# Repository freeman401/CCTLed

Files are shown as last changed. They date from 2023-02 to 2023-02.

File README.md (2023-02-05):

# CCTLed
A simple CCT Led strip driver with IR remote

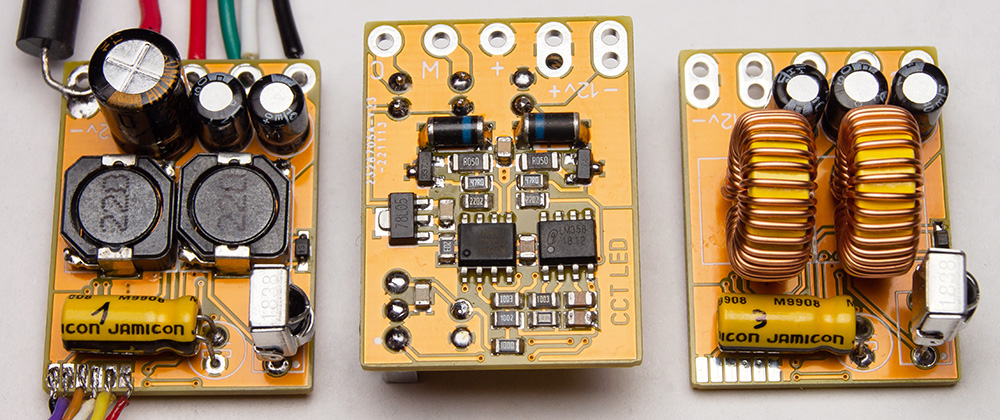
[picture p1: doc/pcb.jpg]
PCB photo(slightly older revision)


## Features and capabilities:
- High PWM frequency, low ripple, low EMI, **no flicker**
- Full range of brightness and temperature control
- Settings are retained in EEPROM
- 12 presets (4 levels of brightness * 3 values of temperature)
- Soft turn-on and turn-off
- Has constant supply current regulation (ultimately the brightness depends on the input voltage)
- Can handle up to ~50W of total maximum output power for 12V led strip (2A per channel)

Higher input voltage can be used, up to 24V, assuming the appropriate input capacitor voltage and proper power consumption calibration.

The driver is supposed to be used with this kind of generic 21-key IR remote:
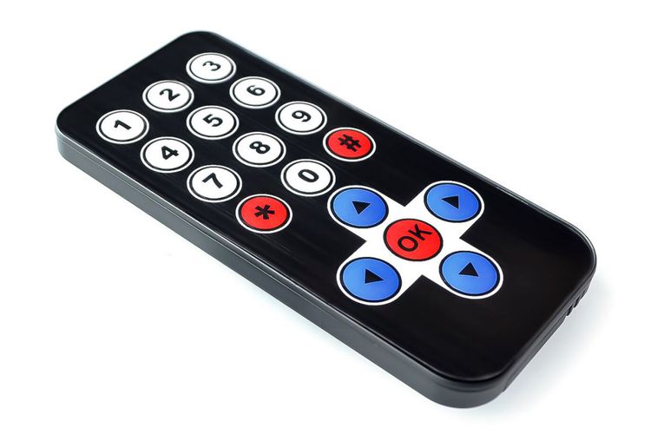
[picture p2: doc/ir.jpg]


Any other NEC protocol remote can be used, appropriate keycodes must be assigned in the firmware.

## Firmware upload
It is recommended to use [Arduino IDE](https://www.arduino.cc/en/software) with an external programmer. [MicroCore](https://github.com/MCUdude/MicroCore) is required. Add a custom clock configuration to 'boards.txt' and select it:
```
13.menu.clock.9M60=9.6 MHz internal osc. 0ms start delay
13.menu.clock.9M60.bootloader.low_fuses=0b0{bootloader.eesave_bit}110010
13.menu.clock.9M60.build.f_cpu=9600000L
```
Otherwise, the driver will blink every time it is turned on. Alternatively, you could solder a 10k resistor in parallel to each mosfet gate to prevent it from opening while the MCU pins are in Hi-z state.

Each driver **needs to be manually calibrated** because it uses the ADC's internal 1.1V reference, which is stable but not at all accurate initially. Calibration values can be loaded from EEPROM (although this is disabled by default).

## Circuit diagram
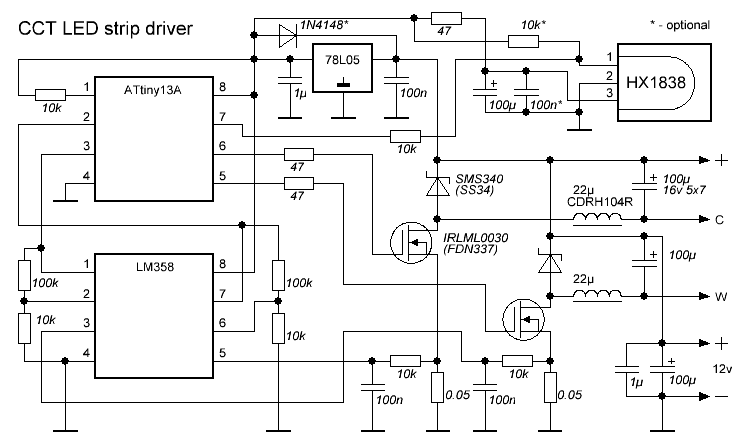
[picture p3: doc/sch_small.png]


Gerber files are provided:

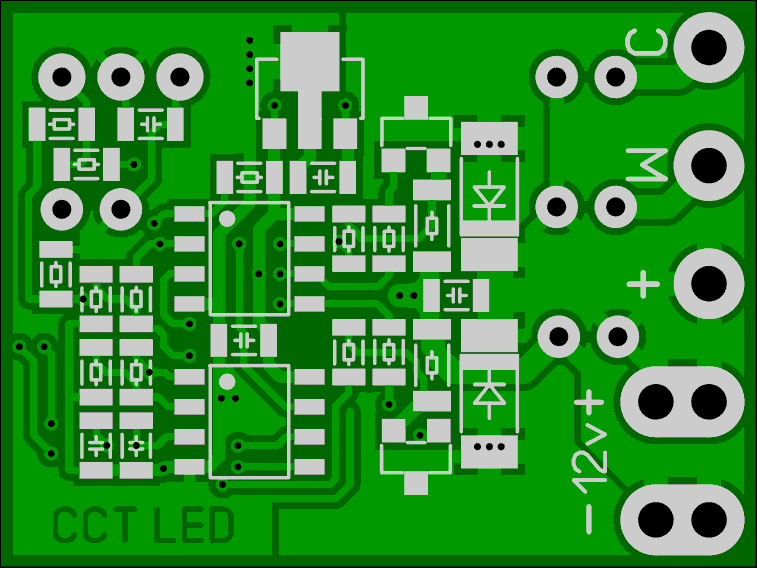
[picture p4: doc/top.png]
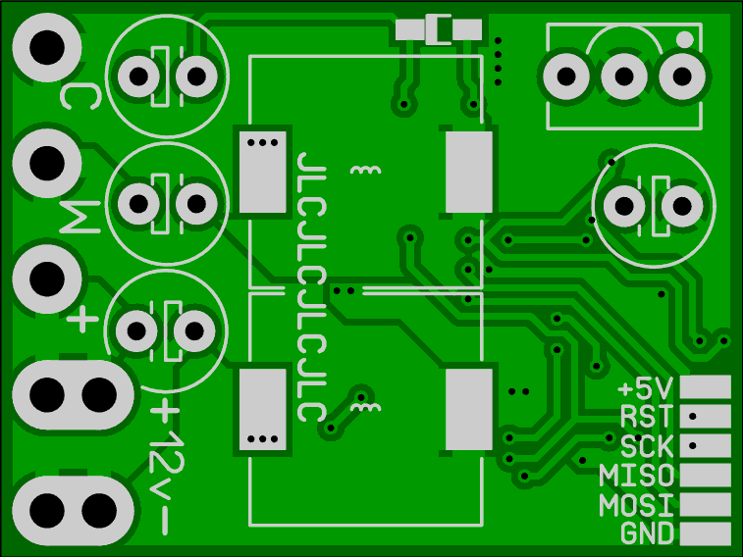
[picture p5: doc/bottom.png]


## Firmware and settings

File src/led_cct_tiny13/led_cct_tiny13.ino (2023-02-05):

/*
CCTLed - A simple CCT Led strip driver with IR remote
Copyright (C) 2023 freeman401
Copyright (C) 2013 FastLED (scale8 routine)
Copyright (C) 2021 AlexGyver (NEC decoding routine)

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
You should have received a copy of the GNU General Public License
along with this program.  If not, see <http://www.gnu.org/licenses/>.
*/

// 141 = ~1a @ vref 1.1v
// [device]: [maxpow] [coeff] - [max current, single strand operating] [max current, both strands operating] ([combined current])
// 1: 220 100 - 1.56a 1.19a (2.38a) @ 18v
// 2: 230 100 - 1.59a 1.19a (2.37a) @ 18v
// 3: 240 130 - 1.69a 1.69a (3.38a) @ 13.3v

//Calibration values:
// MAXPOW is used to set the maximum current of the single channel
// !!! MAXPOW > (255 - coeff) !!!
// Also keep it in 200-249 range; lower - less control precision; higher - regulation loop will break
// Better to calculate a proper resistor divider at lower powers
//
// COEFF is used to adjust the color temperature transition
// < 127 - closer to constant power during entire color temperature range, less light output, more linear temperature regulation
//   127 - full power in the middle of the temperature range, maximum light output, but nonlinear regulation
// > 127 - widens the the middle 'full power' spot, even more nonlinear
#define _MAXPOW       128 //240
#define _COEFF        127 //130

#define USE_EEPROM    0    // Use EEPROM for storage of calibration values, 0 saves 42 bytes

#define _MAXPOW_ADDR  0x00 // Put your settings here with external tools
#define _COEFF_ADDR   0x01

//======================================
#define _BRI_ADDR     0x20
#define _TMP_ADDR     0x21

// IR key codes
#define IR_1          0xA2 // 1010 0010
#define IR_2          0x62 // 0110 0010
#define IR_3          0xE2 // 1110 0010
#define IR_4          0x22 // 0010 0010
#define IR_5          0x02 // 0000 0010
#define IR_6          0xC2 // 1100 0010
#define IR_7          0xE0 // 1110 0000
#define IR_8          0xA8 // 1010 1000
#define IR_9          0x90 // 1001 0000
#define IR_STAR       0x68 // 0110 1000
#define IR_0          0x98 // 1001 1000
#define IR_HASH       0xB0 // 1011 0000
#define IR_UP         0x18 // 0001 1000
#define IR_LEFT       0x10 // 0001 0000
#define IR_OK         0x38 // 0011 1000
#define IR_RIGHT      0x5A // 0101 1010
#define IR_DOWN       0x4A // 0100 1010

const PROGMEM uint8_t acmd[] = { IR_1, IR_2, IR_3, IR_4, IR_5, IR_6, IR_7, IR_8, IR_9, IR_STAR, IR_0, IR_HASH/*, IR_UP, IR_DOWN, IR_LEFT, IR_RIGHT */};
const PROGMEM uint8_t abri[] = { 31, 63, 127, 255 }; // effective values: 31, 31, 31, 63, 63, 63, 127, 127, 127, 255, 255, 255
const PROGMEM uint8_t atmp[] = { 0, 127, 255 }; // effective values: 0, 127, 255, 0, 127, 255, 0, 127, 255, 0, 127, 255

// 1/(37500Hz/3) = 80μs
#define _NEC_TOLERANCE      3   //2   // High/low tolerance, 160μs
#define _NEC_TOLERANCE2     25  //19  // Start/repeat tolerance, 1520μs
#define _NEC_SKIP_REPEAT    0   //2   // First N repeats to skip

// NEC timings
#define _NEC_HIGH_BIT       28  // 2250μs
#define _NEC_LOW_BIT        14  // 1150μs
#define _NEC_START_BIT      169 //180 // 14400μs
#define _NEC_REPEAT         141 //153 // 12300μs
#define _NEC_REPEAT_TIMEOUT 187 // 15000μs

#define _NEC_HIGH_MIN   (_NEC_HIGH_BIT - _NEC_TOLERANCE)
#define _NEC_HIGH_MAX   (_NEC_HIGH_BIT + _NEC_TOLERANCE)
#define _NEC_LOW_MIN    (_NEC_LOW_BIT - _NEC_TOLERANCE)
#define _NEC_LOW_MAX    (_NEC_LOW_BIT + _NEC_TOLERANCE)
#define _NEC_START_MIN  (_NEC_START_BIT - _NEC_TOLERANCE2)
#define _NEC_START_MAX  (_NEC_START_BIT + _NEC_TOLERANCE2)
#define _NEC_REPEAT_MIN (_NEC_REPEAT - _NEC_TOLERANCE2)
#define _NEC_REPEAT_MAX (_NEC_REPEAT + _NEC_TOLERANCE2)

#if USE_EEPROM
  #define __MAXPOW maxpow
  #define __COEFF coeff
#else
  #define __MAXPOW _MAXPOW
  #define __COEFF _COEFF
#endif

uint8_t bufferL = 0;  // Receive buffer, low byte
uint8_t bufferH = 0;  // Receive buffer, high byte
uint8_t command = 0;  // Last received command
uint8_t time = 0;     // Last received pulse width
uint8_t counter = 0;  // Received bits counter
uint8_t repeats = 0;  // Repeats counter
bool start = false;   // Receive start
bool decoded = false; // Command is received, decoded and ready to be interpreted
bool repeat = false;  // Received command is a 'repeat'

uint8_t maxpow = 0;   // Maximum single channel current
uint8_t coeff = 0;    // CCT regulation coefficent
uint8_t upd = 0;      // Skip ADC value update counter
uint8_t adc = 0;      // Averaged ADC value
uint8_t setW = 0;     // Target current setting for warm channel
uint8_t setC = 0;     // Target current setting for cold channel
uint8_t bri = 0;      // Brightness setting
uint8_t tmp = 0;      // Temperature setting
bool toff = false;    // Output is being turned off
uint8_t eet = 0;      // EEPROM save timeout

uint8_t t = 0;        // f/3 divider counter
uint8_t t1 = 0;       // f/256 divider counter

ISR(TIM0_OVF_vect) {
  if(++t > 2) {            // Divide timer frequency by 3
    t = 0;
    if(time < 255) time++; // Measure the IR pulse width
    if(++t1 == 255) {      // Divide it further for EEPROM timeout counter
      t1 = 0;
      if(eet < 255) eet++;
    }
  }
}

ISR(PCINT0_vect) {
  if(PINB & (1 << PB2)) return;             // Falling edge interrupt
  if (start && time > _NEC_LOW_MIN && time < _NEC_HIGH_MAX) {  // Check general pulse width boundaries
    uint8_t state = 2; // This not-so-elegant solution results in a more compact binary for some reason
    if (time < _NEC_LOW_MAX) state = 0;
    if (time > _NEC_HIGH_MIN) state = 1;
    if (state < 2) {                        // Valid low or high bit is received
      bufferL = (bufferL << 1) | state;     // Fill the buffer
      if(counter == 23) bufferH = bufferL;  // High byte is received, continue with low byte
      if (++counter > 31) {                 // 32 bits received
        if (bufferH & bufferL) goto exit;   // Check data integrity
        command = bufferH;                  // Valid command is received
        decoded = true;
        start = false; 
        #if _NEC_SKIP_REPEAT                // Compiler is not smart enough to optimize this
          repeats = 0; 
        #endif 
        goto exit;
      }
    }
  }
  else if (time > _NEC_REPEAT_MIN && time < _NEC_REPEAT_MAX) { // Repeat detected
    #if _NEC_SKIP_REPEAT
      if (++repeats > _NEC_SKIP_REPEAT)
    #endif
      repeat = true;
  } 
  else if (time > _NEC_START_MIN && time < _NEC_START_MAX) {   // Packet start detected
    bufferL = 0;                                               // Reset everything
    counter = 0;
    start = true;
  }
  exit: time = 0;                           // Start measuring the next pulse width
}

ISR(ADC_vect) {  
  adc = adc / 2 + ADCH / 2;                 // Crude 'averaging' technique for better accuracy
  if(TCCR0A & ((1<<WGM01)|(1<<WGM00)) && ++upd > 150 - bri / 2) { // Current regulation should work only if PWM is enabled, also skip ADC cycles for accuracy and smooth fades
    uint8_t* ocrp = (uint8_t*)&OCR0A;       // Pointer to PWM register
    uint8_t* setp = &setW;                  // Pointer to target current value
    if(ADMUX & (1<<MUX0)) {                 // Cool/warm strand channel selection
      ocrp = (uint8_t*)&OCR0B;
      setp = &setC;
    }
    if(*setp < 4) *ocrp = *setp;            // Current regulation at low brightness doesn't go all the way to zero, so it is disabled
    else if(((adc > *setp && adc - *setp > 4) || toff) && *ocrp > 0) (*ocrp)--; // Adjust PWM to match ADC value with current target value
    else if(adc < *setp && *setp - adc > 1 && *ocrp < 255) (*ocrp)++;
    ADMUX ^= (1<<MUX0);                     // Switch to the other ADC channel
    if(toff && !(OCR0A | OCR0B)) {          // If both channels are off, disable PWM to prevent slight residual glow
      toff = false;
      TCCR0A &= ~((1<<WGM01)|(1<<WGM00));
    }
    upd = 0;
  }
  ADCSRA |= (1<<ADSC);                      // Restart ADC measurement
}

uint8_t scale8(uint8_t value, uint8_t scale) {
  volatile uint8_t work = value;                // FASTLED_SCALE8_FIXED == 1; 255/255 -> 255
  //uint8_t work = 0;                         // FASTLED_SCALE8_FIXED == 0; 255/255 -> 254; Not super critical, but saves 26 bytes
  uint8_t cnt = 0x80;
  asm volatile(                             // Some assembly magic here
    "  inc %[scale]                 \n\t"   // FASTLED_SCALE8_FIXED == 1
    "  breq DONE_%=                 \n\t"   // FASTLED_SCALE8_FIXED == 1
    "  clr %[work]                  \n\t"   // FASTLED_SCALE8_FIXED == 1
    "LOOP_%=:                       \n\t"
    "  sbrc %[scale], 0             \n\t"
    "  add %[work], %[i]            \n\t"
    "  ror %[work]                  \n\t"
    "  lsr %[scale]                 \n\t"
    "  lsr %[cnt]                   \n\t"
    "brcc LOOP_%=                   \n\t"
    "DONE_%=:                       \n\t"
    : [work] "+r" (work), [cnt] "+r" (cnt)
    : [scale] "r" (scale), [i] "r" (value)
    :
  );
  return work;
}

void setup() {  
  DDRB   = (1<<PB0)|(1<<PB1); // PB0, PB1 - output
  TCCR0A = (1<<COM0A1)|(1<<COM0B1)|(1<<WGM01)|(1<<WGM00); // Fast PWM timer mode
  TCCR0B = (1<<CS00);         // No prescaler, f=37500Hz
  ADMUX  = (1<<REFS0)|(1<<ADLAR)|(1<<MUX1)|(1<<MUX0);     // ADC3 internal 1.1v reference
  ADCSRA = (1<<ADEN)|(1<<ADSC)|(1<<ADIE)|(0<<ADPS2)|(1<<ADPS1)|(1<<ADPS0); // ADC prescaler - 8, sampling rate - 1171Hz

  EEARL = _BRI_ADDR; // Set up address register
  EECR |= (1<<EERE); // Start eeprom read
  bri = EEDR;        // Restore values from EEPROM
  EEARL = _TMP_ADDR;
  EECR |= (1<<EERE);
  tmp = EEDR;
  #if USE_EEPROM
  EEARL = _MAXPOW_ADDR;
  EECR |= (1<<EERE);
  maxpow = EEDR;
  EEARL = _COEFF_ADDR;
  EECR |= (1<<EERE);
  coeff = EEDR;
  /*
  if(!(maxpow || coeff)) {       // Nice to have, but it doesn't fit
    maxpow = _MAXPOW;
    coeff = _COEFF;
    eewrite(maxpow, coeff, _MAXPOW_ADDR, _COEFF_ADDR);
  }  
  EECR  = (0<<EEPM1)|(0<<EEPM0); // Set Programming mode
  EEARL = _MAXPOW_ADDR;          // Set up address and data registers
  EEDR  = maxpow;
  EECR |= (1<<EEMPE);            // Write logical one to EEMPE
  EECR |= (1<<EEPE);             // Start eeprom write by setting EEPE
  while(EECR & (1<<EEPE));       // Wait for completion of previous write
  EEARL = _COEFF_ADDR;
  EEDR  = coeff;
  EECR |= (1<<EEMPE);
  EECR |= (1<<EEPE);
  */
  #endif

  TIMSK0 = (1<<TOIE0);  // Set up interrupts
  GIMSK  = (1<<PCIE);
  PCMSK  = (1<<PCINT2);
}

void loop() {
  if (repeat || decoded) {                  // Process the received command
    repeat = false;
    if(decoded && command == IR_OK) {
      if(TCCR0A & ((1<<WGM01)|(1<<WGM00)))  // Depending on the PWM state...
        toff = true;                        // Initiate the turn-off cycle...
      else
        TCCR0A |= (1<<WGM01)|(1<<WGM00);    // Or turn it on
    }
    else if (TCCR0A & ((1<<WGM01)|(1<<WGM00))) {     // Prevent change of settings when turned off
      if      (command == IR_UP    && bri < 251) bri += 5;
      else if (command == IR_DOWN  && bri > 4)   bri -= 5;
      else if (command == IR_LEFT  && tmp > 4)   tmp -= 5;
      else if (command == IR_RIGHT && tmp < 251) tmp += 5;
      else {
        uint8_t idx = 0;
        do {                                // Trade some speed for memory efficency
          if(command == pgm_read_byte(&acmd[idx])) { // Look-up the command in the array
            bri = pgm_read_byte(&abri[idx / 4]);     // And retrieve preset values from other arrays
            while(idx >= 3)
              idx -= 3;
            tmp = pgm_read_byte(&atmp[idx]);
            idx = 100;                      // Cheap way to exit the loop
          }
        } while(++idx < 12);        
      }
      eet = 0;                              // Reset the EEPROM write timeout counter to initiate write operation
    }
    decoded = false;
  }

  uint8_t c = __MAXPOW;                     // Calculate the cool/warm channel current for a particular color temperature
  uint8_t w = __MAXPOW;
  if(tmp < (uint8_t)~__COEFF)               // 255 - __COEFF
    c = tmp + scale8(tmp, __MAXPOW - ~__COEFF);
  if(tmp > __COEFF)
    w = ~tmp + scale8(~tmp, __MAXPOW - ~__COEFF);
  setC = scale8(c, bri);                    // Scale the target current values by brigtness
  setW = scale8(w, bri);

  if(eet < 255 && eet > 16) {               // 16 = ~330ms should be enough to ignore all but the last 'repeat' command and prevent unnecessary wear
    EECR  = (0<<EEPM1)|(0<<EEPM0);          // Set Programming mode
    EEARL = _BRI_ADDR;                      // Set up address and data registers
    EEDR  = bri;
    EECR |= (1<<EEMPE);                     // Write logical one to EEMPE
    EECR |= (1<<EEPE);                      // Start eeprom write by setting EEPE
    while(EECR & (1<<EEPE));                // Wait for completion of previous write
    EEARL = _TMP_ADDR;
    EEDR  = tmp;
    EECR |= (1<<EEMPE);
    EECR |= (1<<EEPE);
    eet = 255;                              // Ensure that timeout stays locked
  }
}

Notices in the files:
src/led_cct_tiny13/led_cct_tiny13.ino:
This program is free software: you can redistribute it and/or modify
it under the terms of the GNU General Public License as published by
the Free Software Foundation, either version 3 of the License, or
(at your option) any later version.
